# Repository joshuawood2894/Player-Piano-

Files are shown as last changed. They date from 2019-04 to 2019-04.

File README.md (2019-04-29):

# Player-Piano-
Senior Design Project 2018-2019

Fall 2018/Spring 2019 senior project for the University of Texas in Tyler. Project features a hardware interface that allows a user to control an array of 96 linear solenoids using both MIDI (via micro SD card) and four channels of CV/Gate functionality. Project uses a Teensy 3.6 developement board with its Arm Cortex M4 to control entire real-time system. Repository includes source code and KiCad files (schematic view, PCB view, and Gerber files).

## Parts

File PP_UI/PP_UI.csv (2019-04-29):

Id | Designator | Package | Quantity | Designation | Supplier and ref
1 | ,,,,, | PP_Screw | 6 | PP_Screw
2 | U1 | SOIC-14_3.9x8.7mm_P1.27mm | 1 | TL074
3 | C4,C3,C1,C2 | C_1206_3216Metric_Pad1.42x1.75mm_HandSolder | 4 | 1n
4 | C11,C12,C14,C13 | CP_EIA-3216-18_Kemet-A_Pad1.58x1.35mm_HandSolder | 4 | 100n
5 | R5,R6,R13,R16,R11,R12,R7,R8,R15,R9,R10,R14 | R_1206_3216Metric_Pad1.42x1.75mm_HandSolder | 12 | 24.9k
6 | R2,R3,R4,R1 | R_1206_3216Metric_Pad1.42x1.75mm_HandSolder | 4 | 100k
7 | U2 | SOIC-14_3.9x8.7mm_P1.27mm | 1 | MCP6004
8 | C5,C6,C7,C8,C9,C10 | C_1206_3216Metric_Pad1.42x1.75mm_HandSolder | 6 | .01u
9 | J1,J2,J3,J4,J6,J7,J8,J9 | THONKICONN | 8 | AudioJack2_Ground_Switch
10 | Q1,Q2,Q3,Q4 | TO-92_Inline | 4 | 2N7000
11 | R17,R18,R19,R20,R21,R22,R23,R24,R25,R26,R29,R30 | R_1206_3216Metric_Pad1.42x1.75mm_HandSolder | 12 | 10k
12 | R27,R28,R31,R32 | R_1206_3216Metric_Pad1.42x1.75mm_HandSolder | 4 | 47k
13 | SW1,SW2,SW3 | Push_E-Switch_KS01Q01 | 3 | SW_Push
14 | SW4 | RotaryEncoder_Alps_EC11E-Switch_Vertical_H20mm | 1 | Rotary_Encoder_Switch
15 | J10 | PinHeader_2x10_P2.54mm_Vertical | 1 | Conn_02x10_Counter_Clockwise
16 | U3 | SOIC-14_3.9x8.7mm_P1.27mm | 1 | 40106
17 | J5 | PinSocket_1x04_P2.54mm_Vertical | 1 | Conn_01x04_Female

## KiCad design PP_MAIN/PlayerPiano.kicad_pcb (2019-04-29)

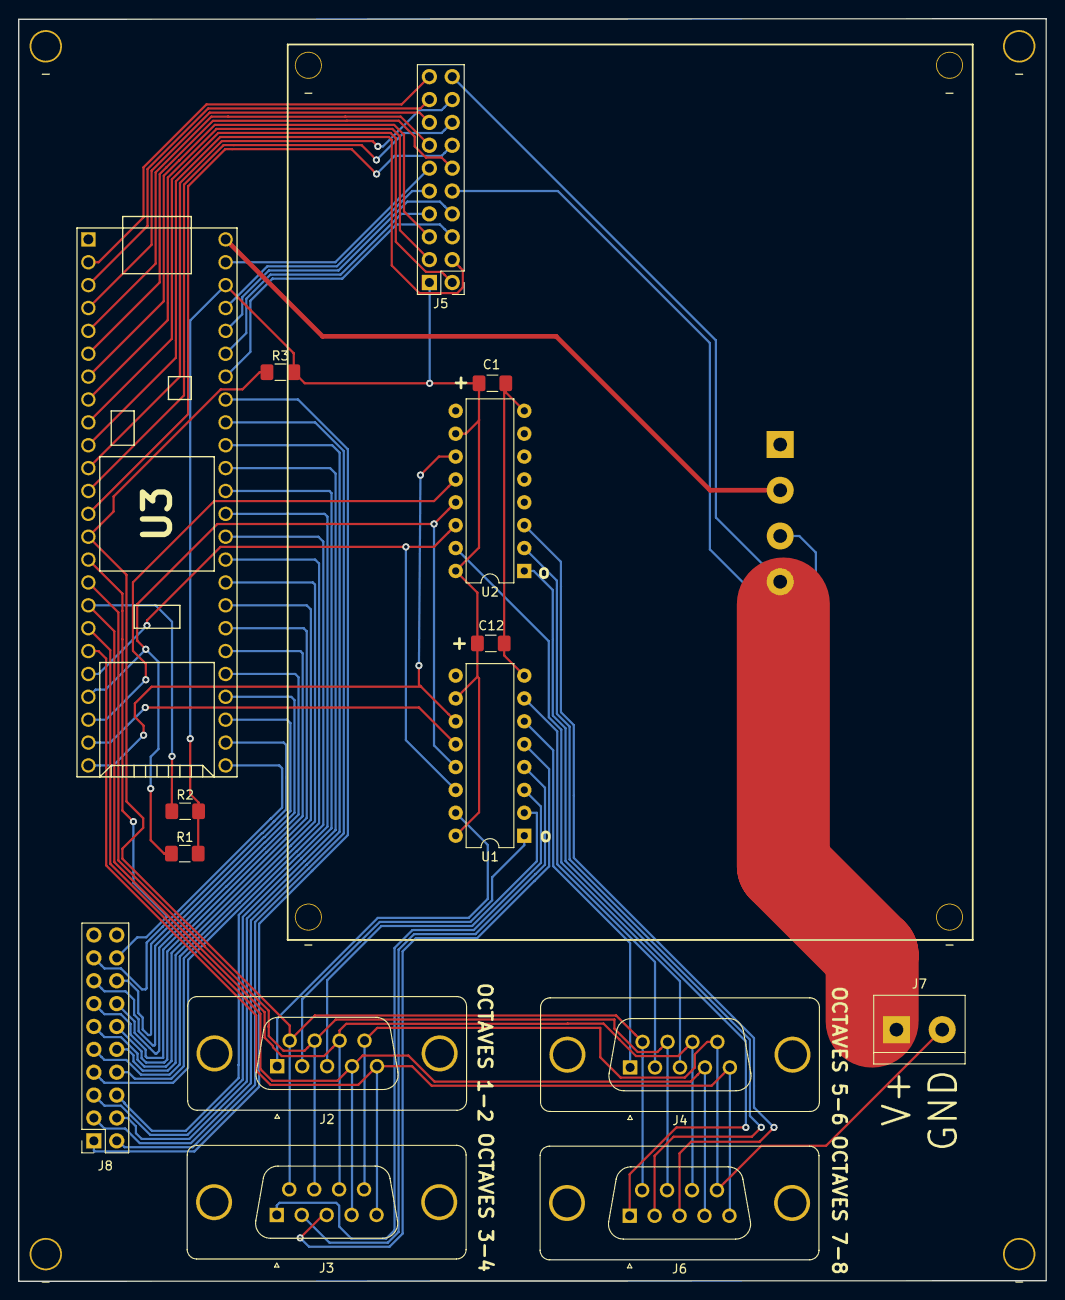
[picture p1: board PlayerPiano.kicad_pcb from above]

Board: 2 copper layers, 114.1 x 140.2 mm, 24 parts (1 on the bottom side), 61 nets.

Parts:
C1: CP1; C_1206_3216Metric_Pad1.42x1.75mm_HandSolder
C12: 100n; C_1206_3216Metric_Pad1.42x1.75mm_HandSolder
J1: Screw_Terminal_01x04; TerminalBlock_bornier-4_P5.08mm
J2, J3, J4, J6: Conn_01x09; DSUB-9_Female_Vertical_P2.77x2.84mm_MountingHoles
J5: Conn_02x10_Counter_Clockwise; PinHeader_2x10_P2.54mm_Vertical
J7: Screw_Terminal_01x02; TerminalBlock_bornier-2_P5.08mm
J8: Conn_02x10_Counter_Clockwise; PinSocket_2x10_P2.54mm_Vertical
R1, R2, R3: 47k; R_1206_3216Metric_Pad1.42x1.75mm_HandSolder
U1, U2: 74HC595; DIP-16_W7.62mm
U3: Teensy3.6; Teensy35_36
_: PP_Screw
_#2, _#3, _#4, _#5, _#6, _#7, _#8: PP_Screw

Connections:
/+3V3: C1.1, C12.1, J5.1, R1.2, R2.2, R3.2, U1.10, U1.16, U2.10, U2.16, U3.51
/+5V: J1.2, U3.53
/+12V: J1.4, J5.20, J7.1
/-12V: J1.3, J5.10
/GND: C1.2, C12.2, J1.1, J2.9, J3.9, J4.9, J5.11, J6.9, J7.2, U1.8, U2.8, U3.1, U3.52
Enc_A: J5.19, U3.2
Enc_B: J5.18, U3.11
Enc_SW: J5.17, U3.3
FAULT: J2.6, J3.6, J4.6, J6.6, R3.1, U3.14
Gate_A: J5.2, U3.9
Gate_B: J5.3, U3.8
Gate_C: J5.4, U3.10
Gate_D: J5.5, U3.7
Midi_Play_Pause: J5.16, U3.12
Midi_Stop: J5.15, U3.4
Midi_loop: J5.14, U3.13
unnamed: J2.1, U1.15
unnamed: J2.2, U1.1
unnamed: J2.3, U1.2
unnamed: J3.1, U1.3
unnamed: J3.2, U1.4
unnamed: J3.3, U1.5
unnamed: J4.1, U1.6
unnamed: J4.2, U1.7
unnamed: J4.3, U2.15
unnamed: J6.1, U2.1
unnamed: J6.2, U2.2
unnamed: J6.3, U2.3
unnamed: J8.1, U3.46
unnamed: J8.2, U3.45
unnamed: J8.3, U3.44
unnamed: J8.4, U3.43
unnamed: J8.5, U3.42
unnamed: J8.6, U3.41
unnamed: J8.7, U3.40
unnamed: J8.8, U3.39
unnamed: J8.9, U3.38
unnamed: J8.10, U3.37
unnamed: J8.11, U3.36
unnamed: J8.12, U3.35
unnamed: J8.13, U3.34
unnamed: J8.14, U3.33
unnamed: J8.15, U3.32
unnamed: J8.16, U3.31
unnamed: J8.17, U3.30
PITCH_A: J5.6, U3.47
PITCH_B: J5.7, U3.48
PITCH_C: J5.8, U3.49
PITCH_D: J5.9, U3.50
RESET: J2.7, J3.7, J4.7, J6.7, U3.16
SCL_Display: J5.13, U3.5
SDA_Display: J5.12, U3.6
SER_CLK: J2.4, J3.4, J4.4, J6.4, U3.18
SER_DATA: J2.5, J3.5, J4.5, J6.5, U3.19
SRSEL_CLK: U1.11, U2.11, U3.24
SRSEL_DATA: U1.14, U2.14, U3.20
SRSEL_ENABLE: R1.1, U1.13, U2.13, U3.21
SRSEL_LATCH_A: U1.12, U3.23
SRSEL_LATCH_B: U2.12, U3.22
nENBL: J2.8, J3.8, J4.8, J6.8, R2.1, U3.17
xtra_3V3: J8.18, U3.15

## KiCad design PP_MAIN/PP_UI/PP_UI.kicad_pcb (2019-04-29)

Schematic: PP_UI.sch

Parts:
C1, C2, C3, C4: 1n; C_1206_3216Metric_Pad1.42x1.75mm_HandSolder
C5, C6, C7, C8, C9, C10: .01u; C_1206_3216Metric_Pad1.42x1.75mm_HandSolder
C11, C12, C13: 100n; CP_EIA-3216-18_Kemet-A_Pad1.58x1.35mm_HandSolder
J1, J2, J3, J4, J6, J7, J8, J9: AudioJack2_Ground_Switch; THONKICONN
J5: Conn_01x04_Female; PinHeader_1x04_P2.54mm_Vertical
J10: Conn_02x10_Counter_Clockwise; PinHeader_2x10_P2.54mm_Vertical
J11, J12, J13, J14, J15, J16, J17, J18, J19, J20, J21, J22, J23, J24: Conn_02x12_Odd_Even; PinHeader_2x12_P2.54mm_Vertical
Q1, Q2, Q3, Q4: 2N7000; TO-92_Inline
R1, R2, R3, R4: 100k; R_1206_3216Metric_Pad1.42x1.75mm_HandSolder
R5, R6, R7, R8, R9, R10, R11, R12, R13, R14, R15, R16: 24.9k; R_1206_3216Metric_Pad1.42x1.75mm_HandSolder
R17, R18, R19, R20, R21, R22, R23, R24, R25, R26, R29, R30: 10k; R_1206_3216Metric_Pad1.42x1.75mm_HandSolder
R27, R28, R31, R32: 47k; R_1206_3216Metric_Pad1.42x1.75mm_HandSolder
SW1, SW2, SW3: SW_Push; Push_E-Switch_KS01Q01
SW4: Rotary_Encoder_Switch; RotaryEncoder_Alps_EC11E-Switch_Vertical_H20mm
U1: TL074; DIP-14_W8.89mm_SMDSocket_LongPads
U2: MCP6004; DIP-14_W8.89mm_SMDSocket_LongPads
U3: 40106; DIP-14_W8.89mm_SMDSocket_LongPads

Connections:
/+3V3: C11.1, C13.1, J5.1, J10.1, Q1.3, Q2.3, Q3.3, Q4.3, R17.2, R18.2, R19.2, R23.2, R24.2, R29.1, U2.4 (V+), U3.14
/GND: C5.2, C6.2, C7.2, C8.2, C9.2, C10.2, C11.2, C13.2, J5.2, J10.11, R27.2, R28.2, R31.2, R32.2, SW1.1, SW2.1, SW3.1, SW4.C, SW4.S2, U1.2 (-), U1.6 (-), U1.9 (-), U1.13 (-), U2.2 (-), U2.6 (-), U2.9 (-), U2.11 (V-), U2.13 (-), U3.7
/VCC: C12.1, J10.20, U1.4 (V+)
/VEE: C12.2, J10.10, U1.11 (V-)
Enc_A: J10.19, U3.4
Enc_B: J10.18, U3.6
Enc_SW: J10.17, U3.2
Gate_A: J10.2, Q1.1, R27.1
Gate_B: J10.3, Q3.1, R31.1
Gate_C: J10.4, Q2.1, R28.1
Gate_D: J10.5, Q4.1, R32.1
Midi_Play_Pause: J10.16, U3.12
Midi_Stop: J10.15, U3.8
Midi_loop: J10.14, U3.10
unnamed: C1.2, R9.1, R13.2, U2.3 (+)
unnamed: C2.2, R10.1, R14.2, U2.5 (+)
unnamed: C3.2, R11.1, R15.2, U2.10 (+)
unnamed: C4.2, R12.1, R16.2, U2.12 (+)
unnamed: C5.1, R20.1, U3.13
unnamed: C6.1, R21.1, U3.9
unnamed: C7.1, R22.1, U3.11
unnamed: C8.1, R25.2, U3.3
unnamed: C9.1, R26.2, U3.5
unnamed: C10.1, R30.1, U3.1
unnamed: J11.1, J17.1
unnamed: J11.2, J17.2
unnamed: J11.3, J17.3
unnamed: J11.4, J17.4
unnamed: J11.5, J17.5
unnamed: J11.6, J17.6
unnamed: J11.7, J17.7
unnamed: J11.8, J17.8
unnamed: J11.9, J17.9
unnamed: J11.10, J17.10
unnamed: J11.11, J17.11
unnamed: J11.12, J17.12
unnamed: J11.13, J17.13
unnamed: J11.14, J17.14
unnamed: J11.15, J17.15
unnamed: J11.16, J17.16
unnamed: J11.17, J17.17
unnamed: J11.18, J17.18
unnamed: J11.19, J17.19
unnamed: J11.20, J17.20
unnamed: J11.21, J17.21
unnamed: J11.22, J17.22
unnamed: J11.23, J17.23
unnamed: J11.24, J17.24
unnamed: R1.1, R5.2, U1.3 (+)
unnamed: R2.1, R6.2, U1.5 (+)
unnamed: R3.1, R7.2, U1.10 (+)
unnamed: R4.1, R8.2, U1.12 (+)
unnamed: R5.1, R9.2, U1.1
unnamed: R6.1, R10.2, U1.7
unnamed: R7.1, R11.2, U1.8
unnamed: R8.1, R12.2, U1.14
unnamed: R17.1, R20.2, SW1.2
unnamed: R18.1, R21.2, SW2.2
unnamed: R19.1, R22.2, SW3.2
unnamed: R23.1, R25.1, SW4.A
unnamed: R24.1, R26.1, SW4.B
unnamed: R29.2, R30.2, SW4.S1
PITCH_A: C1.1, J10.6, R13.1, U2.1
PITCH_B: C2.1, J10.7, R14.1, U2.7
PITCH_C: C3.1, J10.8, R15.1, U2.8
PITCH_D: C4.1, J10.9, R16.1, U2.14
SCL_Display: J5.3, J10.13
SDA_Display: J5.4, J10.12

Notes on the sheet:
MIDI BUTTONS
ENCODER W/ SW
GATE INPUTS
CV INPUTS
DISPLAY
OCTAVE TEMINALS

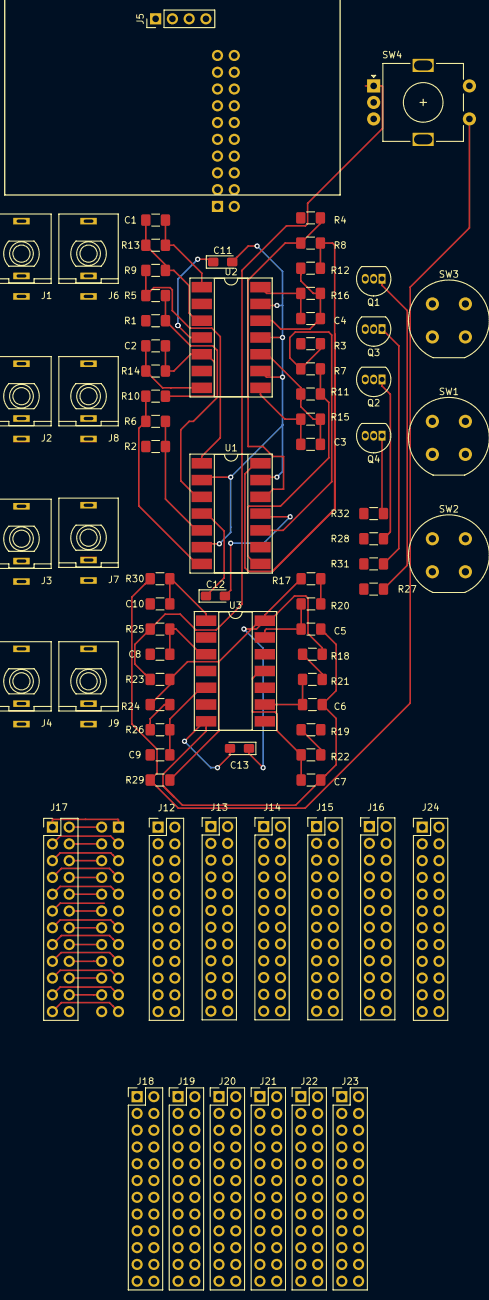
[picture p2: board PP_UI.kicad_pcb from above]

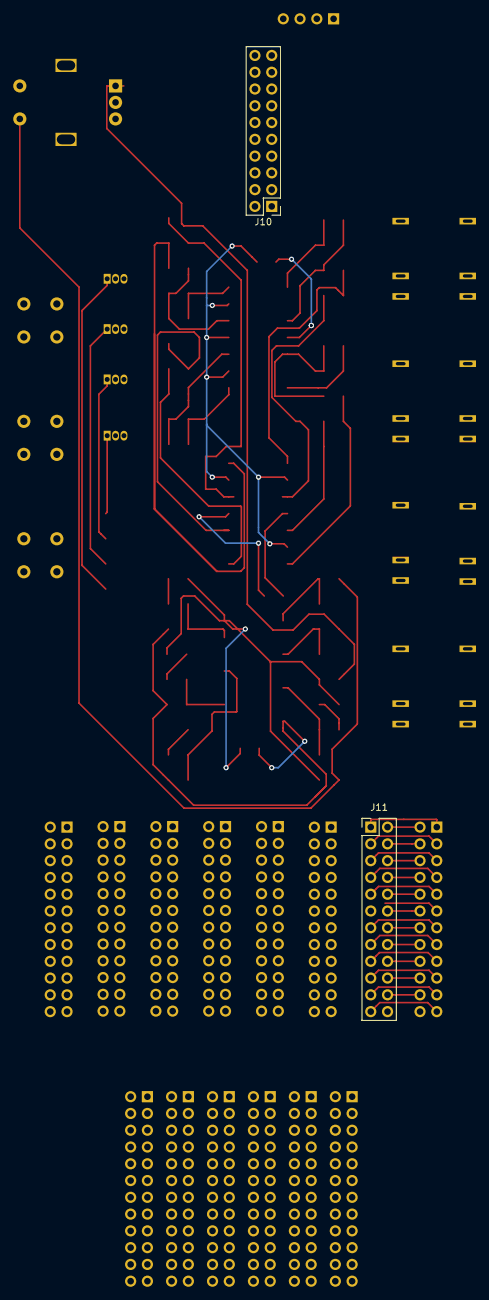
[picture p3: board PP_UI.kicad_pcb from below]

Board: 2 copper layers, 80 parts (2 on the bottom side), 68 nets.

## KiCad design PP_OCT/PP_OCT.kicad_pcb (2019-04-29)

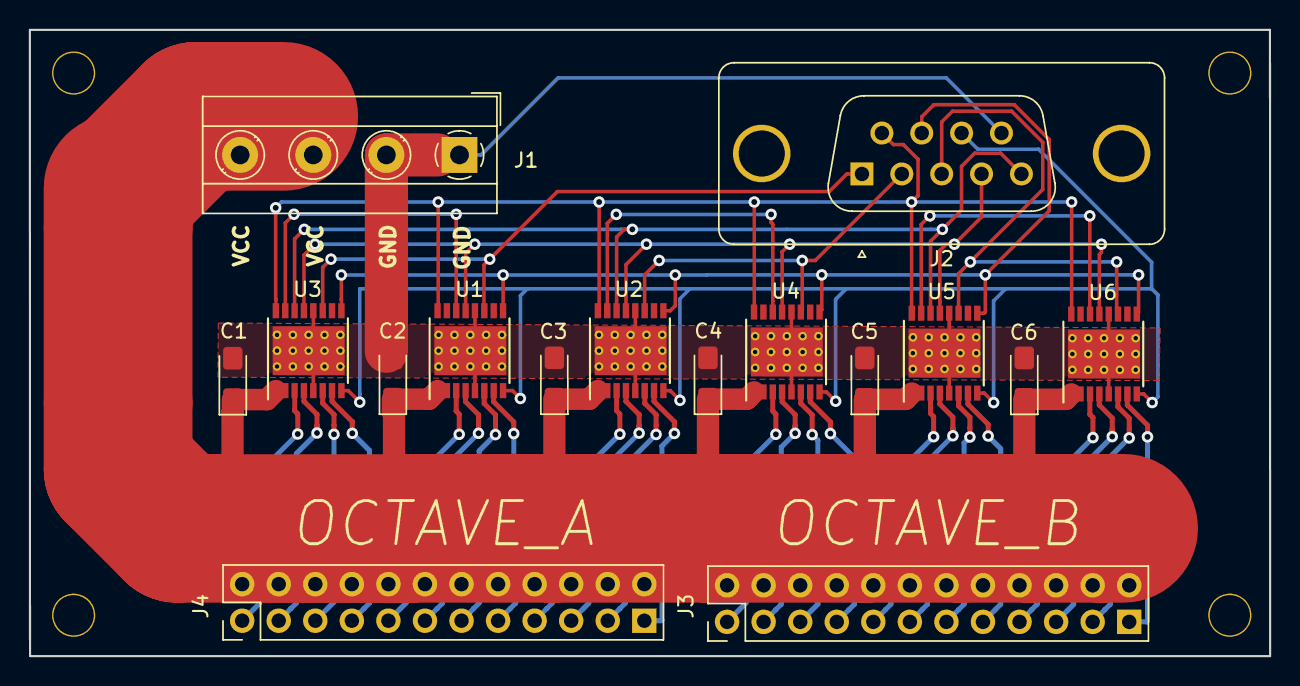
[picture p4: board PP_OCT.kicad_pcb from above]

Board: 2 copper layers, 86.2 x 43.5 mm, 16 parts (0 on the bottom side), 37 nets.

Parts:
C1, C2, C3, C4, C5, C6: CP; CP_EIA-3216-10_Kemet-I_Pad1.58x1.35mm_HandSolder
J1: Screw_Terminal_01x04; TerminalBlock_MetzConnect_Type101_RT01604HBWC_1x04_P5.08mm_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
J2: Conn_01x09; DSUB-9_Female_Vertical_P2.77x2.84mm_MountingHoles
J3, J4: Conn_02x12_Odd_Even; PinSocket_2x12_P2.54mm_Vertical
U1, U2, U3, U4, U5, U6: DRV8804; HTSSOP-16-1EP_4.4x5mm_P0.65mm_EP3.4x5mm_Mask3x3mm_ThermalVi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

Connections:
/GND: C1.2, C2.2, C3.2, C4.2, C5.2, C6.2, J1.1, J1.2, J2.9, U1.5, U1.12, U1.17, U2.5, U2.12, U2.17, U3.5, U3.12, U3.17, U4.5, U4.12, U4.17, U5.5, U5.12, U5.17, U6.5, U6.12, U6.17
/VCC: C1.1, C2.1, C3.1, C4.1, C5.1, C6.1, J1.3, J1.4, J3.2, J3.4, J3.6, J3.8, J3.10, J3.12, J3.14, J3.16, J3.18, J3.20, J3.22, J3.24, J4.2, J4.4, J4.6, J4.8, J4.10, J4.12, J4.14, J4.16, J4.18, J4.20, J4.22, J4.24, U1.1, U1.2, U2.1, U2.2, U3.1, U3.2, U4.1, U4.2, U5.1, U5.2, U6.1, U6.2
FAULT: J2.6, U1.16, U2.16, U3.16, U4.16, U5.16, U6.16
LATCH_A: J2.1, U1.11, U3.11
LATCH_B: J2.2, U2.11, U4.11
LATCH_C: J2.3, U5.11, U6.11
unnamed: J3.1, U6.7
unnamed: J3.3, U6.6
unnamed: J3.5, U6.4
unnamed: J3.7, U6.3
unnamed: J3.9, U5.7
unnamed: J3.11, U5.6
unnamed: J3.13, U5.4
unnamed: J3.15, U5.3
unnamed: J3.17, U4.7
unnamed: J3.19, U4.6
unnamed: J3.21, U4.4
unnamed: J3.23, U4.3
unnamed: J4.1, U2.7
unnamed: J4.3, U2.6
unnamed: J4.5, U2.4
unnamed: J4.7, U2.3
unnamed: J4.9, U1.7
unnamed: J4.11, U1.6
unnamed: J4.13, U1.4
unnamed: J4.15, U1.3
unnamed: J4.17, U3.7
unnamed: J4.19, U3.6
unnamed: J4.21, U3.4
unnamed: J4.23, U3.3
unnamed: U1.14, U3.15
unnamed: U2.15, U4.14
unnamed: U5.15, U6.14
RESET: J2.7, U1.9, U2.9, U3.9, U4.9, U5.9, U6.9
SER_CLK: J2.4, U1.13, U2.13, U3.13, U4.13, U5.13, U6.13
SER_DATA: J2.5, U2.14, U3.14, U5.14
nENBL: J2.8, U1.8, U2.8, U3.8, U4.8, U5.8, U6.8

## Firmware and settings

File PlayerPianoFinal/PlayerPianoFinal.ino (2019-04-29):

#include <Adafruit_ssd1306syp.h>
#include <SPI.h>
#include <SdFat.h>
#include <MD_MIDIFile.h>
#include <Bounce2.h>
#include <EEPROM.h>

#define SERIAL_RATE 57600 //use for printing to serial monitor

//Output pins from the Teensy
#define SCL_PIN 3   //Display I2C 
#define SDA_PIN 4   //Display I2C 
#define encButton 1 //Encoder button
#define encoderA 0  //Encoder rotate left
#define encoderB 9  //Encoder rotate right

#define SRclockPin 26       //Driver clock
#define SRenablePin 25      //Driver enable
#define SRdataPin 27        //Driver data
#define SRSELclockPin 32    //Selection shift reg clock
#define SRSELenablePin 29   //Selection shift reg enable
#define SRSELdataPin 28     //Selection shift reg data
#define SRSELlatchPin_1 31  //Selection shift reg latchA
#define SRSELlatchPin_2 30  //Selection shift reg latchB

#define loopButton 11 //Loop button
#define playButton 10 //Play button
#define stopButton 2  //Stop button

//Input pins from the Teensy
#define Gate_1 7    //Gate 1
#define CV_1 20     //Potentiometer control
#define Gate_2 6    //rGate 2
#define CV_2 21     //no input
#define Gate_3 8    //Gate 3
#define CV_3 22     //no input
#define Gate_4 5    //Gate 4
#define CV_4 23     //true CV input

//Setting required display and MIDI variables
Adafruit_ssd1306syp display(SDA_PIN, SCL_PIN);
SdFatSdio sd; //Teensy 3.6
SdFile file;
MD_MIDIFile SMF;

//Setting debounce variables
Bounce debounceLoop = Bounce();
Bounce debouncePlay = Bounce();
Bounce debounceStop = Bounce();
Bounce debounceEnc = Bounce();

int numberOfFiles;    //number of files on SD card
char currentFileName[13] = {};    //holds file name for display
const char loopOn[13] = {'L', 'o', 'o', 'p', 'O', 'N'}; //For loop on indication
//For mode of operation indication
const char modeText[15] = {'M', 'I', 'D', 'I', 'C', 'V', '/', 'G', 'a', 't', 'e', 'M', 'o', 'd', 'e'};
int encCounter = 0;   //dial position of encoder
int encState;         //current state of encoder dial
int encLastState;     //previous state of encoder dial
byte midiStatus = 0;  //0_default
                      //1/2_play/pause
                      //3_stop
byte loopStatus = 0;  //0_off
                      //1_on
byte modeStatus = 0;  //0_MIDI//
                      //1_CV/Gate                 
int wasPaused = 0;    //Goes high when paused
int solenoidCount = 0; //number of active solenoids
const int maxSolenoid = 15; //max number of active solenoids
unsigned long buttonPressTimeStamp; //Time of button press
int offAry[24] = {0}; //For deactivation of all solenoids
int CVAry1_2[24] = {0};  //Octave1_2 solenoid statuses
int CVAry3_4[24] = {0};  //Octave3_4 solenoid statuses
int CVAry5_6[24] = {0};  //Octave5_6 solenoid statuses
int CVAry7_8[24] = {0};  //Octave7 solenoid statuses
int Note1;  //CV1 note
int Note2;  //CV2 note
int Note3;  //CV3 note
int Note4;  //CV4 note
float CV1min; //min used CV1 value
float CV1inc; //change in CV1 per note
float CV2min; //min used CV2 value
float CV2inc; //change in CV2 per note
float CV3min; //min used CV3 value
float CV3inc; //change in CV3 per note
float CV4min; //min used CV4 value
float CV4inc; //change in CV4 per note

//values of for each note
int octaves1_2[24] = {0x24, 0x25, 0x26, 0x27, 0x28, 0x29, 0x2a, 0x2b, 0x2c, 0x2d, 0x2e, 0x2f,
                     0x30, 0x31, 0x32, 0x33, 0x34, 0x35, 0x36, 0x37, 0x38, 0x39, 0x3a, 0x3b};
int octaves3_4[24] = {0x3c, 0x3d, 0x3e, 0x3f, 0x40, 0x41, 0x42, 0x43, 0x44, 0x45, 0x46, 0x47,
                     0x48, 0x49, 0x4a, 0x4b, 0x4c, 0x4d, 0x4e, 0x4f, 0x50, 0x51, 0x52, 0x53};
int octaves5_6[24] = {0x54, 0x55, 0x56, 0x57, 0x58, 0x59, 0x5a, 0x5b, 0x5c, 0x5d, 0x5e, 0x5f,
                     0x60, 0x61, 0x62, 0x63, 0x64, 0x65, 0x66, 0x67, 0x68, 0x69, 0x6a, 0x6b};
int octaves7_8[24] = {0x6c, 0x6d, 0x6e, 0x6f, 0x70, 0x71, 0x72, 0x73, 0x74, 0x75, 0x76, 0x77,
                     0x78, 0x79, 0x7a, 0x7b, 0x7c, 0x7d, 0x7e, 0x7f, 0x80, 0x81, 0x82, 0x83};

int latchAry1[8] = {1, 1, 1, 1, 1, 1, 1, 1}; //initial latchA values
int latchAry2[8] = {1, 1, 1, 1, 1, 1, 1, 1}; //initial latchB values

/**************************************************************************/
void setup() {
  //delay for display initialization. Just safety precaution
  delay(1000);
  display.initialize();

  //set pin mode for outputs
  pinMode(SRclockPin, OUTPUT); 
  pinMode(SRdataPin, OUTPUT);
  pinMode(SRSELclockPin, OUTPUT);
  pinMode(SRSELdataPin, OUTPUT);
  pinMode(SRSELlatchPin_1, OUTPUT);
  pinMode(SRSELlatchPin_2, OUTPUT);
  pinMode(SRSELenablePin, OUTPUT);
  midiSilence(); //Ensure solendoids begin off
  pinMode(SRenablePin, OUTPUT);

  //set pin mode for inputs
  pinMode (encoderA, INPUT);
  pinMode (encoderB, INPUT);
  attachInterrupt(digitalPinToInterrupt(encButton), ISR_encoderSW, RISING);
  attachInterrupt(digitalPinToInterrupt(playButton), ISR_play_pause, RISING);
  attachInterrupt(digitalPinToInterrupt(stopButton), ISR_stop, RISING);
  attachInterrupt(digitalPinToInterrupt(loopButton), ISR_loop, RISING);
  pinMode (CV_1, INPUT);
  pinMode (CV_2, INPUT);
  pinMode (CV_3, INPUT);
  pinMode (CV_4, INPUT);

  analogReadResolution(13); //set ADC read resolution

  //Pull CV1 calibration values from EEPROM
  union
  {
    byte b[sizeof(CV1min)];
    float f;
  } temp;
  for (unsigned int i = 0; i < sizeof(temp); i++)
  {
    temp.b[i] = EEPROM.read(i);
  }
  CV1min = temp.f;
  for (unsigned int i = 0; i < sizeof(temp); i++)
  {
    temp.b[i] = EEPROM.read(4 + i);
  }
  CV1inc = temp.f;
  CV1min = CV1min - (CV1inc/2);
  
  //Pull CV2 calibration values from EEPROM
  for (unsigned int i = 0; i < sizeof(temp); i++)
  {
    temp.b[i] = EEPROM.read(8 + i);
  }
  CV2min = temp.f;
  for (unsigned int i = 0; i < sizeof(temp); i++)
  {
    temp.b[i] = EEPROM.read(12 + i);
  }
  CV2inc = temp.f;
  CV2min = CV2min - (CV2inc/2);

  //Pull CV3 calibration values from EEPROM
  for (unsigned int i = 0; i < sizeof(temp); i++)
  {
    temp.b[i] = EEPROM.read(16 + i);
  }
  CV3min = temp.f;
  for (unsigned int i = 0; i < sizeof(temp); i++)
  {
    temp.b[i] = EEPROM.read(20 + i);
  }
  CV3inc = temp.f;
  CV3min = CV3min - (CV3inc/2);

  //Pull CV4 calibration values from EEPROM
  for (unsigned int i = 0; i < sizeof(temp); i++)
  {
    temp.b[i] = EEPROM.read(24 + i);
  }
  CV4min = temp.f;
  for (unsigned int i = 0; i < sizeof(temp); i++)
  {
    temp.b[i] = EEPROM.read(28 + i);
  }
  CV4inc = temp.f;
  CV4min = CV4min - (CV4inc/2);

  //Set button debouncing
  debouncePlay.attach(loopButton);
  debouncePlay.interval(50);
  debouncePlay.attach(playButton);
  debouncePlay.interval(50);
  debounceStop.attach(stopButton);
  debounceStop.interval(50);
  debounceEnc.attach(encButton);
  debounceEnc.interval(50);

  //initialize encoder
  encLastState = digitalRead(encoderA);
  sdInitAndExtract();
  
  //Fill the currentFileName array with first file on card on power on or reset
  sd.vwd()->rewind();
  if (file.openNext(sd.vwd(), O_READ)) {
    file.close();
    if (file.openNext(sd.vwd(), O_READ)) {
      file.getName(currentFileName, 13);
      file.close();
    }
  }

  //Using the Serial.begin() while using the display slows things down
  //Toggle use for testing
  Serial.begin(SERIAL_RATE);

  //initialize MIDI
  SMF.begin(&sd);
  SMF.setMidiHandler(midiCallback);
}

/**************************************************************************/
void loop() {
  switch (modeStatus) {
            //MIDI Mode of operation
    case 0: //MIDI Mode of operation
            //MIDI Mode of operation
      int error;
      switch (midiStatus) {
        case 0: //MIDI idle
          updateEncoder();
          updateDisplay();
          break;
        case 1: //MIDI play
          SMF.setFilename(currentFileName);
          error = SMF.load(); //load file check
          if (error != -1) {  //file not loaded
            display.clear();
            display.setTextSize(2);
            display.setTextColor(WHITE);
            display.setCursor(0, 0);
            display.print("Error:");
            display.setTextSize(1);
            display.setCursor(0, 16);
            display.print("File could not be \nloaded");
            display.update();
            delay(2000);
          }
          else {  //play loaded file
            while (!SMF.isEOF()) {
              if (SMF.getNextEvent()) {
                if (midiStatus == 2) { //if paused
                  midiOffTemp();
                  wasPaused = 1;
                  SMF.pause(true);
                }
                if (midiStatus == 3) { //if stopped
                  midiSilence();
                  solenoidCount = 0;
                  break;
                }
                updateEncoder();
                updateDisplay();
              }
              updateEncoder();
              updateDisplay();
            }
          }
          SMF.close(); //file ends
          solenoidCount = 0;
          midiStatus = 0;
          break;
        case 3: //MIDI stop
          SMF.restart();
          solenoidCount = 0;
          midiStatus = 0;
          wasPaused = 0;
          break;
      }
      break;
            //
    case 1: //CV/Gate Mode of operation
            //
      updateDisplay();
      break;
  }
}

/**************************************************************************/

/*  This function is an interrupt routine triggered by a positive pulse from
    the play button. It causes the value of midiStatus to toggle between 1
    and 2. These values are used in the switch/case in the main loop() to
    give this button both play and pause functionality.
*/
void ISR_play_pause() {
  if (midiStatus == 1) {
    midiStatus = 2;
  }
  else {
    midiStatus = 1;
    SMF.pause(false);
  }
}

/*  Works the same as the play/pause interrupt routine except it uses the stop
     button.
*/
void ISR_stop() {
  midiStatus = 3;
  buttonPressTimeStamp = millis();
  SMF.pause(false);
  attachInterrupt(digitalPinToInterrupt(stopButton), ISR_mode, FALLING);
}

/*  Works the same as the play/pause interrupt routine except it uses the loop
    button.
*/
void ISR_loop()
{
  if (modeStatus == 0)
  {
    if (loopStatus == 0)
    {
      SMF.looping(true);
      loopStatus = 1;
    }
    else
    {
      SMF.looping(false);
      loopStatus = 0;
    }
  }
}

/*  Interupt that is triggered when the stop button is released.
    Determines if the button was held long enough to go into
    CV calibration (30 seconds) or switch modes of operation (3 seconds).
*/
void ISR_mode()
{
  buttonPressTimeStamp = millis()-buttonPressTimeStamp;
  if (buttonPressTimeStamp > 30000) //run CV calibration
  {
    runCalibration();
  }
  else if (buttonPressTimeStamp > 3000) //change operating mode
  {
    if (modeStatus == 0) //CV/Gate mode on
    {
      attachInterrupt(digitalPinToInterrupt(Gate_1), ISR_Gate_1_ON, HIGH);
      attachInterrupt(digitalPinToInterrupt(Gate_2), ISR_Gate_2_ON, HIGH);
      attachInterrupt(digitalPinToInterrupt(Gate_3), ISR_Gate_3_ON, HIGH);
      attachInterrupt(digitalPinToInterrupt(Gate_4), ISR_Gate_4_ON, HIGH);
      modeStatus = 1;
    }
    else //MIDI mode on
    {
      detachInterrupt(digitalPinToInterrupt(Gate_1));
      detachInterrupt(digitalPinToInterrupt(Gate_2));
      detachInterrupt(digitalPinToInterrupt(Gate_3));
      detachInterrupt(digitalPinToInterrupt(Gate_4));
      modeStatus = 0;
      midiSilence();
    }
  }
  attachInterrupt(digitalPinToInterrupt(stopButton), ISR_stop, RISING);
}

/*  This function calibrates the CV inputs to function properly
    with the intended audio controlling device.
*/
void runCalibration()
{ 
  //Turn off interupts
  detachInterrupt(digitalPinToInterrupt(encButton));
  detachInterrupt(digitalPinToInterrupt(playButton));
  detachInterrupt(digitalPinToInterrupt(stopButton));
  detachInterrupt(digitalPinToInterrupt(loopButton));
  detachInterrupt(digitalPinToInterrupt(Gate_1));
  detachInterrupt(digitalPinToInterrupt(Gate_2));
  detachInterrupt(digitalPinToInterrupt(Gate_3));
  detachInterrupt(digitalPinToInterrupt(Gate_4));

  int playState = 0;  //Denotes when play is pressed
  int stopState = 0;  //Denotes when stop is pressed
  int sampleFlag = 0; //Exits while loop after button press
  float CVLow = 0;    //Lower control voltage
  float CVHigh = 0;   //Upper control voltage
  float CVperNote;    //Change in CV/note
  union
  {
    byte b[sizeof(CVLow)];
    float f;
  } temp;             //variable can be used as float or byte

  //First prompt to continue calibration
  display.clear();
  display.setCursor(0, 0);
  display.print("CV CALIBRATION");
  display.setCursor(0, 16);
  display.print("CAUTION:Press STOP to");
  display.setCursor(0, 24);
  display.print("return. Calibration");
  display.setCursor(0, 32);
  display.print("must be completed");
  display.setCursor(0, 40);
  display.print("once begun. Press");
  display.setCursor(0, 48);
  display.print("PLAY to continue");
  display.update();
  delay(1000);

  //Wait for button press
  while (!sampleFlag)
  {
    playState = digitalRead(playButton);
    stopState = digitalRead(stopButton);
    if (stopState) //Return from calibration
    {
      attachInterrupt(digitalPinToInterrupt(encButton), ISR_encoderSW, RISING);
      attachInterrupt(digitalPinToInterrupt(playButton), ISR_play_pause, RISING);
      attachInterrupt(digitalPinToInterrupt(stopButton), ISR_stop, RISING);
      attachInterrupt(digitalPinToInterrupt(loopButton), ISR_loop, RISING);
      attachInterrupt(digitalPinToInterrupt(Gate_1), ISR_Gate_1_ON, HIGH);
      attachInterrupt(digitalPinToInterrupt(Gate_2), ISR_Gate_2_ON, HIGH);
      attachInterrupt(digitalPinToInterrupt(Gate_3), ISR_Gate_3_ON, HIGH);
      attachInterrupt(digitalPinToInterrupt(Gate_4), ISR_Gate_4_ON, HIGH);
      return;
    }
    if (playState) //Continue calibration
    {
      sampleFlag = 1;
    }
  }

  sampleFlag = 0; //reset flag

  //Second prompt to continue calibration
  display.clear();
  display.setCursor(0, 0);
  display.print("CV CALIBRATION");
  display.setCursor(0, 16);
  display.print("Are you sure you wish");
  display.setCursor(0, 24);
  display.print("to continue?  THIS IS");
  display.setCursor(0, 32);
  display.print("YOUR FINAL CHANCE");
  display.setCursor(0, 40);
  display.print("TO RETURN. Press PLAY");
  display.setCursor(0, 48);
  display.print("to continue");
  display.setCursor(0, 56);
  display.print("calibration");
  display.update();
  delay(1000);

  //Wait for button press
  while (!sampleFlag)
  {
    playState = digitalRead(playButton);
    stopState = digitalRead(stopButton);
    if (stopState)
    {
      attachInterrupt(digitalPinToInterrupt(encButton), ISR_encoderSW, RISING);
      attachInterrupt(digitalPinToInterrupt(playButton), ISR_play_pause, RISING);
      attachInterrupt(digitalPinToInterrupt(stopButton), ISR_stop, RISING);
      attachInterrupt(digitalPinToInterrupt(loopButton), ISR_loop, RISING);
      attachInterrupt(digitalPinToInterrupt(Gate_1), ISR_Gate_1_ON, HIGH);
      attachInterrupt(digitalPinToInterrupt(Gate_2), ISR_Gate_2_ON, HIGH);
      attachInterrupt(digitalPinToInterrupt(Gate_3), ISR_Gate_3_ON, HIGH);
      attachInterrupt(digitalPinToInterrupt(Gate_4), ISR_Gate_4_ON, HIGH);
      return;
    }
    if (playState)
    {
      sampleFlag = 1;
    }
  }

  sampleFlag = 0; //reset flag

  //Prompt for lower CV on input 1
  display.clear();
  display.setCursor(0, 0);
  display.print("CV CALIBRATION");
  display.setCursor(0, 20);
  display.print("Apply 2V to CV1 and");
  display.setCursor(0, 28);
  display.print("press Play");
  display.update();
  delay(1000);

  //Wait for button press
  while (!sampleFlag)
  {
    sampleFlag = digitalRead(playButton);
  }

  //Sample CV input and get average
  for (int i = 0; i < 100; i++)
  {
    CVLow = CVLow + (analogRead(CV_1)*3.3/8192)*10000;
  }
  CVLow = CVLow/100;
  CV1min = CVLow;
  temp.f = CVLow;
  for (unsigned int i = 0; i < sizeof(temp); i++)
  {
    EEPROM.write(i, temp.b[i]);
  }
  
  sampleFlag = 0; //Reset flag

  display.clear();
  display.setCursor(0, 0);
  display.print("CV CALIBRATION");
  display.setCursor(30, 20);
  display.print("WAIT");
  display.update();
  delay(2000);

  //Prompt for upper CV on input 1
  display.clear();
  display.setCursor(0, 0);
  display.print("CV CALIBRATION");
  display.setCursor(0, 20);
  display.print("Apply 4V to CV1 and");
  display.setCursor(0, 28);
  display.print("press Play");
  display.update();

  //Wait for button press
  while (!sampleFlag)
  {
    sampleFlag = digitalRead(playButton);
  }

  //Sample CV input and get average
  for (int i = 0; i < 100; i++)
  {
    CVHigh = CVHigh + (analogRead(CV_1)*3.3/8192)*10000;
  }
  CVHigh = CVHigh/100;
  CVperNote = (CVHigh - CVLow)/24;
  CV1inc = CVperNote;
  CV1min = CV1min - (CV1inc/2);
  temp.f = CVperNote;
  for (unsigned int i = 0; i < sizeof(temp); i++)
  {
    EEPROM.write(4+i, temp.b[i]);
  }

  //Reset values
  sampleFlag = 0;
  CVLow = 0;
  CVHigh = 0;

  display.clear();
  display.setCursor(0, 0);
  display.print("CV CALIBRATION");
  display.setCursor(30, 20);
  display.print("WAIT");
  display.update();
  delay(2000);

  //Prompt for lower CV on input 2
  display.clear();
  display.setCursor(0, 0);
  display.print("CV CALIBRATION");
  display.setCursor(0, 20);
  display.print("Apply 2V to CV2 and");
  display.setCursor(0, 28);
  display.print("press Play");
  display.update();
  delay(1000);

  //Wait for button press
  while (!sampleFlag)
  {
    sampleFlag = digitalRead(playButton);
  }

  //Sample CV input and get average
  for (int i = 0; i < 100; i++)
  {
    CVLow = CVLow + (analogRead(CV_2)*3.3/8192)*10000;
  }
  CVLow = CVLow/100;
  CV2min = CVLow;
  temp.f = CVLow;
  for (unsigned int i = 0; i < sizeof(temp); i++)
  {
    EEPROM.write(8+i, temp.b[i]);
  }
  
  sampleFlag = 0; //reset flag

  display.clear();
  display.setCursor(0, 0);
  display.print("CV CALIBRATION");
  display.setCursor(30, 20);
  display.print("WAIT");
  display.update();
  delay(2000);

  //Prompt for upper CV on input 2
  display.clear();
  display.setCursor(0, 0);
  display.print("CV CALIBRATION");
  display.setCursor(0, 20);
  display.print("Apply 4V to CV2 and");
  display.setCursor(0, 28);
  display.print("press Play");
  display.update();

  //Wait for button press
  while (!sampleFlag)
  {
    sampleFlag = digitalRead(playButton);
  }

  //Sample CV input and get average
  for (int i = 0; i < 100; i++)
  {
    CVHigh = CVHigh + (analogRead(CV_2)*3.3/8192)*10000;
  }
  CVHigh = CVHigh/100;
  CVperNote = (CVHigh - CVLow)/24;
  CV2inc = CVperNote;
  CV2min = CV2min - (CV2inc/2);
  temp.f = CVperNote;
  for (unsigned int i = 0; i < sizeof(temp); i++)
  {
    EEPROM.write(12+i, temp.b[i]);
  }

  //Reset values
  sampleFlag = 0;
  CVLow = 0;
  CVHigh = 0;

  display.clear();
  display.setCursor(0, 0);
  display.print("CV CALIBRATION");
  display.setCursor(30, 20);
  display.print("WAIT");
  display.update();
  delay(2000);

  //Prompt for lower CV on input 3
  display.clear();
  display.setCursor(0, 0);
  display.print("CV CALIBRATION");
  display.setCursor(0, 20);
  display.print("Apply 2V to CV3 and");
  display.setCursor(0, 28);
  display.print("press Play");
  display.update();
  delay(1000);

  //Wait for button press
  while (!sampleFlag)
  {
    sampleFlag = digitalRead(playButton);
  }

  //Sample CV input and get average
  for (int i = 0; i < 100; i++)
  {
    CVLow = CVLow + (analogRead(CV_3)*3.3/8192)*10000;
  }
  CVLow = CVLow/100;
  CV3min = CVLow;
  temp.f = CVLow;
  for (unsigned int i = 0; i < sizeof(temp); i++)
  {
    EEPROM.write(16+i, temp.b[i]);
  }
  
  sampleFlag = 0; //reset flag

  display.clear();
  display.setCursor(0, 0);
  display.print("CV CALIBRATION");
  display.setCursor(30, 20);
  display.print("WAIT");
  display.update();
  delay(2000);

  //Prompt for upper CV on input 3
  display.clear();
  display.setCursor(0, 0);
  display.print("CV CALIBRATION");
  display.setCursor(0, 20);
  display.print("Apply 4V to CV3 and");
  display.setCursor(0, 28);
  display.print("press Play");
  display.update();

  //Wait for button press
  while (!sampleFlag)
  {
    sampleFlag = digitalRead(playButton);
  }

  //Sample CV input and get average
  for (int i = 0; i < 100; i++)
  {
    CVHigh = CVHigh + (analogRead(CV_3)*3.3/8192)*10000;
  }
  CVHigh = CVHigh/100;
  CVperNote = (CVHigh - CVLow)/24;
  CV3inc = CVperNote;
  CV3min = CV3min - (CV3inc/2);
  temp.f = CVperNote;
  for (unsigned int i = 0; i < sizeof(temp); i++)
  {
    EEPROM.write(20+i, temp.b[i]);
  }

  //reset values
  sampleFlag = 0;
  CVLow = 0;
  CVHigh = 0;

  display.clear();
  display.setCursor(0, 0);
  display.print("CV CALIBRATION");
  display.setCursor(30, 20);
  display.print("WAIT");
  display.update();
  delay(2000);

  //Prompt for lower CV on input 4
  display.clear();
  display.setCursor(0, 0);
  display.print("CV CALIBRATION");
  display.setCursor(0, 20);
  display.print("Apply 2V to CV4 and");
  display.setCursor(0, 28);
  display.print("press Play");
  display.update();
  delay(1000);

  //Wait for button press
  while (!sampleFlag)
  {
    sampleFlag = digitalRead(playButton);
  }

  //Sample CV input and get average
  for (int i = 0; i < 100; i++)
  {
    CVLow = CVLow + (analogRead(CV_4)*3.3/8192)*10000;
  }
  CVLow = CVLow/100;
  CV4min = CVLow;
  temp.f = CVLow;
  for (unsigned int i = 0; i < sizeof(temp); i++)
  {
    EEPROM.write(24+i, temp.b[i]);
  }
  
  sampleFlag = 0; //reset flag

  display.clear();
  display.setCursor(0, 0);
  display.print("CV CALIBRATION");
  display.setCursor(30, 20);
  display.print("WAIT");
  display.update();
  delay(2000);

  //Prompt for upper CV on input 4
  display.clear();
  display.setCursor(0, 0);
  display.print("CV CALIBRATION");
  display.setCursor(0, 20);
  display.print("Apply 4V to CV4 and");
  display.setCursor(0, 28);
  display.print("press Play");
  display.update();

  //Wait for button press
  while (!sampleFlag)
  {
    sampleFlag = digitalRead(playButton);
  }
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

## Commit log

2019-04-29 Arduino Sketch File
2019-04-29 KiCad files for OCTAVE PCB
    [PP_OCT.kicad_pcb, PP_OCT.sch]
2019-04-29 KiCad files for USER INTERFACE PCB
    [PP_UI.csv, PP_UI.kicad_pcb, PP_UI.sch]
2019-04-29 KiCad files for MAIN PCB
    [Dual Attenuverter.kicad_pcb, Dual Attenuverter.sch, PP_UI.kicad_pcb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]
2019-04-29 Gerber and Drill files for all three PCBs
    [PP_OCT-B.Cu.gbr, PP_OCT-B.Mask.gbr, PP_OCT-B.Paste.gbr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]
2019-04-29 Documentation (bill of materials, user manual, etc.)
